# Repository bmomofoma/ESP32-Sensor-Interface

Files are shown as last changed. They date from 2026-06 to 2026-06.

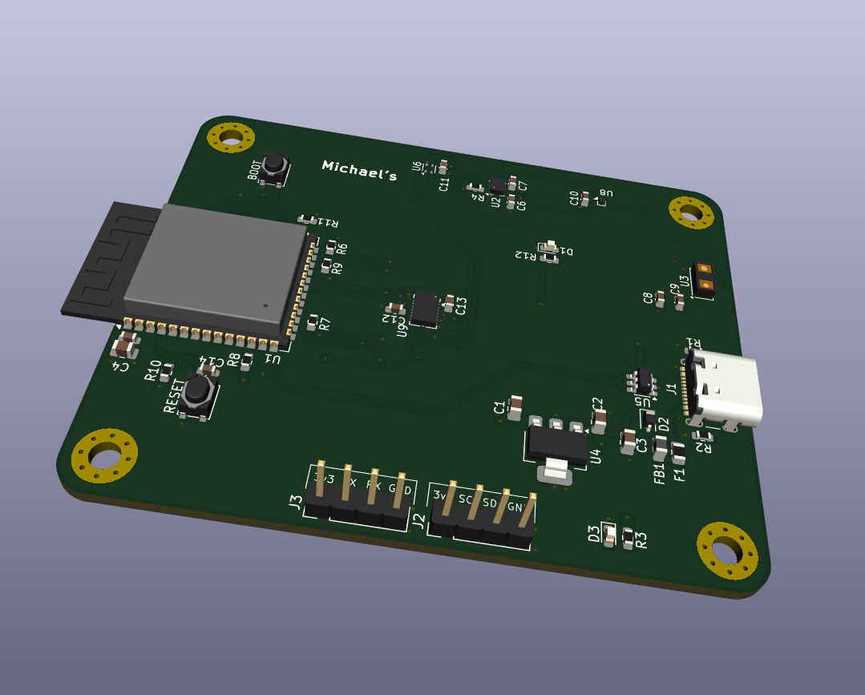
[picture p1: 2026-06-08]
assets/PCB view.png

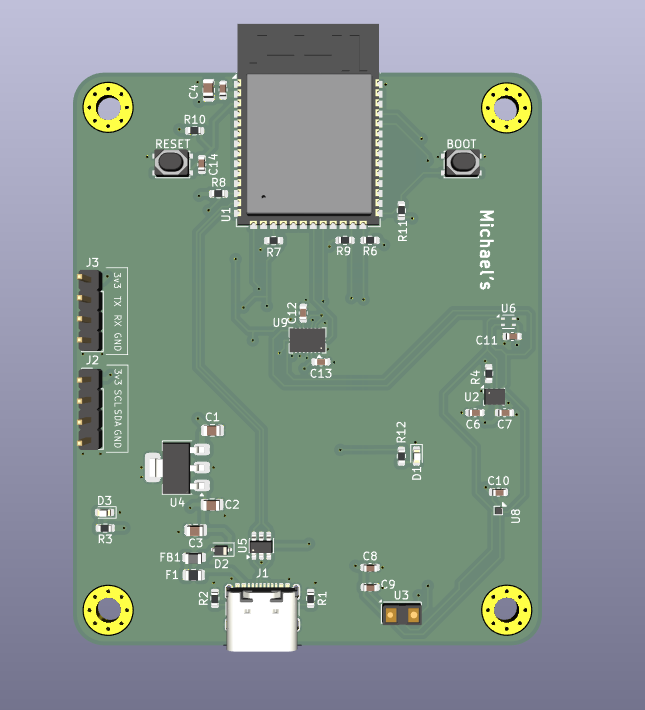
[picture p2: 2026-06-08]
assets/PCB top view.png

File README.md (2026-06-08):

# ESP32-S3 Sensor Hub

I built this board because I wanted a compact, reliable hardware platform that could pull data from five different sensors at the same time without turning the signal lines into a noisy mess. It’s a 4-layer board centered around an ESP32-S3 that acts as a central data hub, ideal for robotics or autonomous systems. 

---

## Why I Made These Design Choices

### Moving to a 4-Layer Board
A lot of simple projects stick to 2 layers, but running high-frequency data lines right next to power traces is a recipe for a noisy bus. 
* I made **Layer 2 a solid Ground plane** to give all the signals a tight, clean return path, which knocks down cross-talk immensely.
* **Layer 3 is a power plane**, which lets me cleanly route the 3.3V regulated line without running into routing bottlenecks.

### Powering the Array Safely
The board takes 5V from a USB-C port and drops it to 3.3V using an `AP7361C-33E` linear regulator. 
* The ESP32-S3 spikes in current when its Wi-Fi or Bluetooth radios kick on. This regulator can handle up to 1A, keeping the rail steady so the sensors don't glitch.
* For debugging safety, I put a ferrite bead, a Schottky diode, and a resettable polyfuse on the input to protect the expensive components downstream if I accidentally short something on the bench.

### Choosing Flat Pads (ENIG) over HASL
Two of the sensors—the `BMI088` IMU and the `MMC5633NJL` magnetometer—come in fine-pitch LGA and QFN packages, meaning the pins are tiny and sit entirely underneath the chip. 
* Standard HASL board finishes leave uneven mounds of solder on the pads, which causes these tiny chips to float or bridge during soldering. 
* I specified an **ENIG (Gold) finish** for manufacturing because it guarantees perfectly flat pads, making reflow much easier.

---

## The Hardware Setup

All five sensors communicate over a single shared $\text{I}^2\text{C}$ bus using **GPIO8 (SDA)** and **GPIO9 (SCL)**, pulled up by $4.7\text{ k}\Omega$ resistors.

| Sensor | Part Number | What It Measures |
| :--- | :--- | :--- |
| **IMU (6-Axis)** | BMI088 | Pitch, roll, yaw, and high-G acceleration |
| **Magnetometer** | MMC5633NJL | Compass heading orientation |
| **Pressure/Altimeter** | BMP280 | Altitude & atmospheric pressure |
| **Temp/Humidity** | SHT4x | Local environmental data |
| **Time-of-Flight (ToF)** | VL53L0X | Precision optical distance for proximity |

> 🛠️ **Hardware Note:** The VL53L0X distance sensor hardcodes itself to address `0x29` on boot, which can cause bus issues. To fix this, I routed its hardware shutdown pin (**XSHUT**) to **GPIO48** so the firmware can hard-reset the chip and dynamically change its address if needed.

---

## Layout Constraints & Debugging

* **Antenna Keep-Out:** There is a strict, cross-hatched keep-out zone on all layers around the ESP32’s PCB antenna. No copper, traces, or mounting screws can go near it, keeping the wireless signal strong.
* **Lab Debugging Headers:** I exposed the $\text{I}^2\text{C}$ lines on header **J2** and the main serial UART lines on header **J3**. This makes it easy to clip on a logic analyzer or hook up a USB-to-UART bridge to watch terminal logs while writing firmware.
* **Buttons & LEDs:** Included a reset button, a boot button, a green power LED, and a red status LED mapped to **GPIO3** for basic visual debugging.

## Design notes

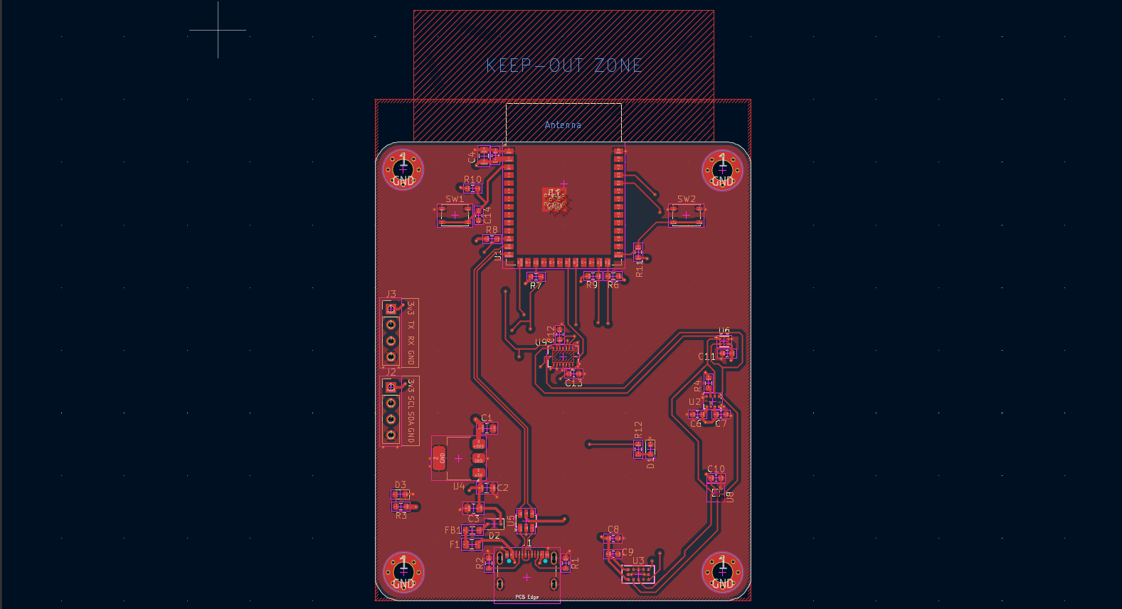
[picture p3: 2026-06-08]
assets/PCB-top-layer.png

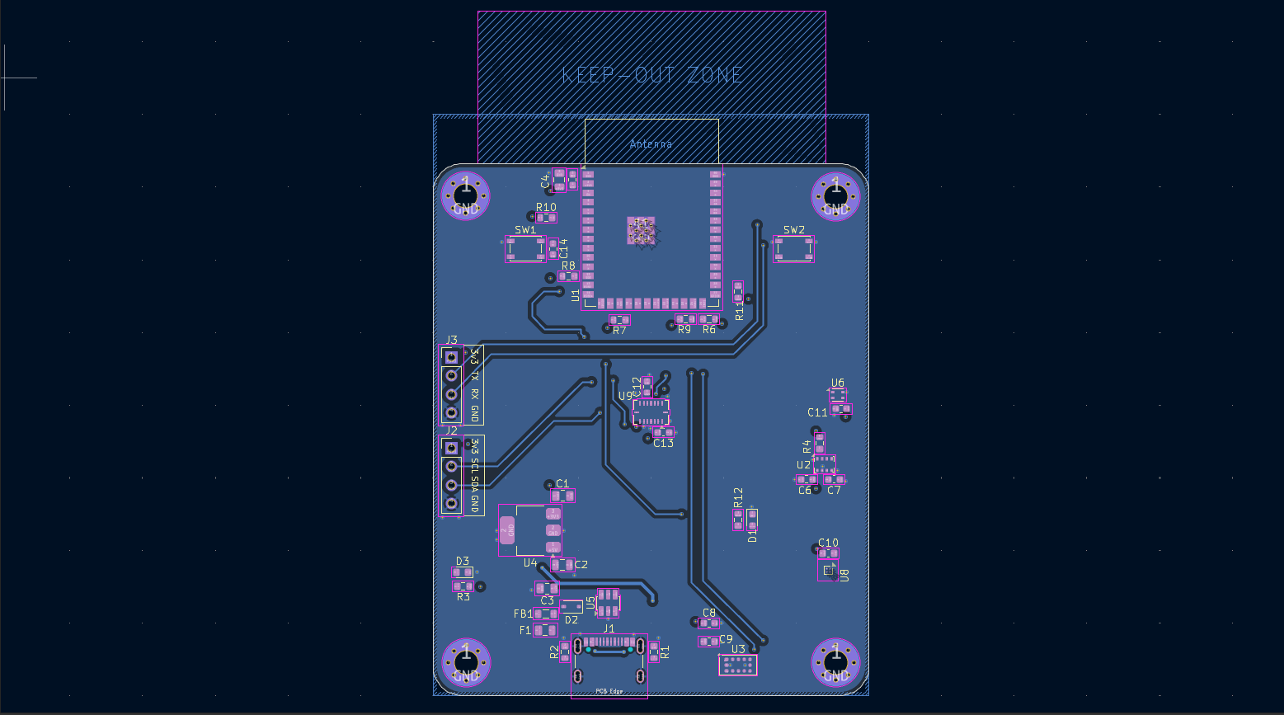
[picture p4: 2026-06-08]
assets/pcb-bottom-layer.png

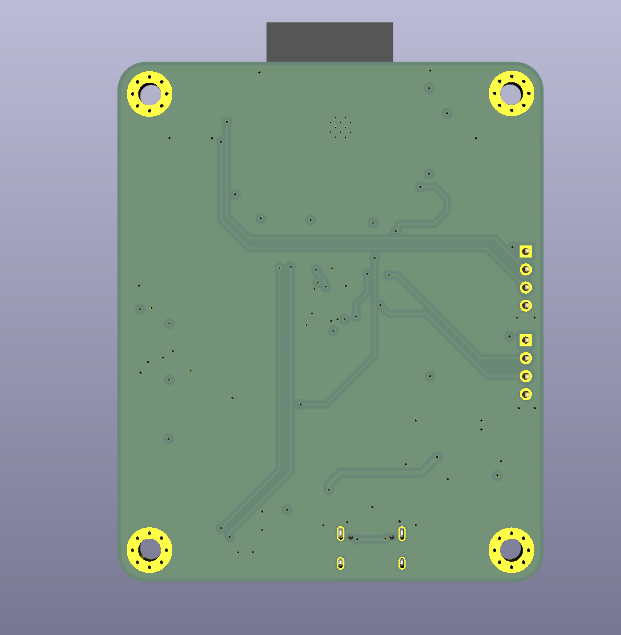
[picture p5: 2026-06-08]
assets/PCB bottom view.png

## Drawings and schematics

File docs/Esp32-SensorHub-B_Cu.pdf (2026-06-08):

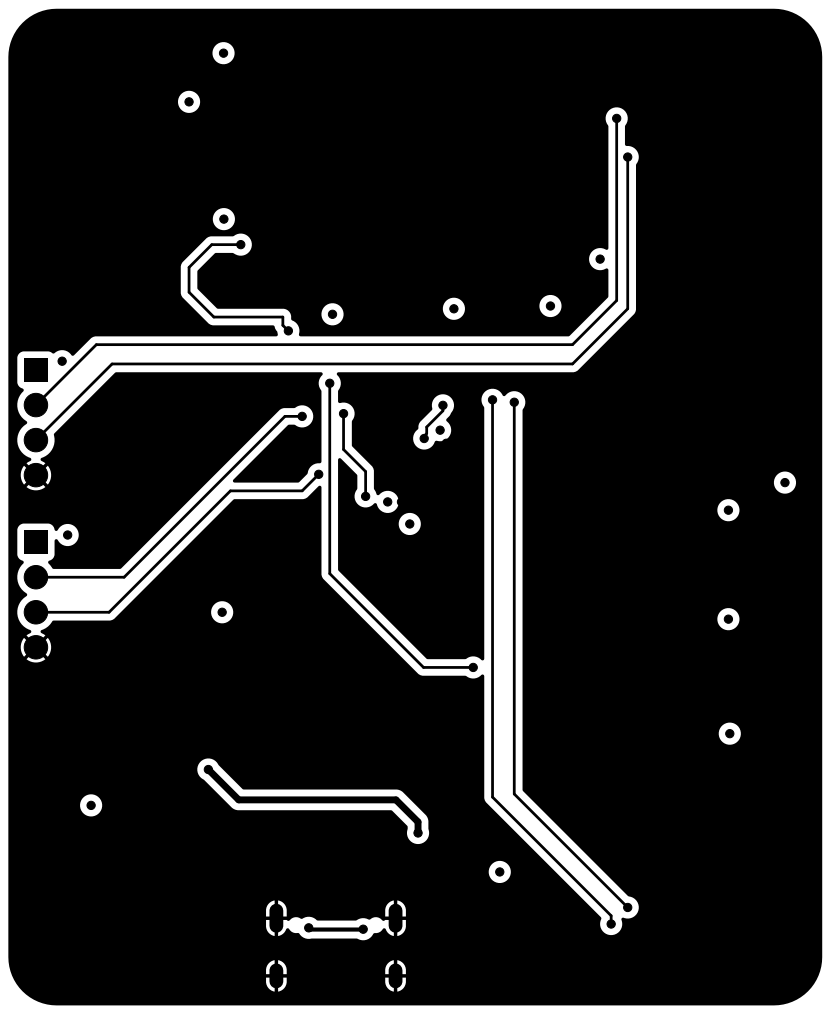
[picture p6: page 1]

Size: A4 | Rev:
KiCad E.D.A. 10.0.2 | Id: 4/5

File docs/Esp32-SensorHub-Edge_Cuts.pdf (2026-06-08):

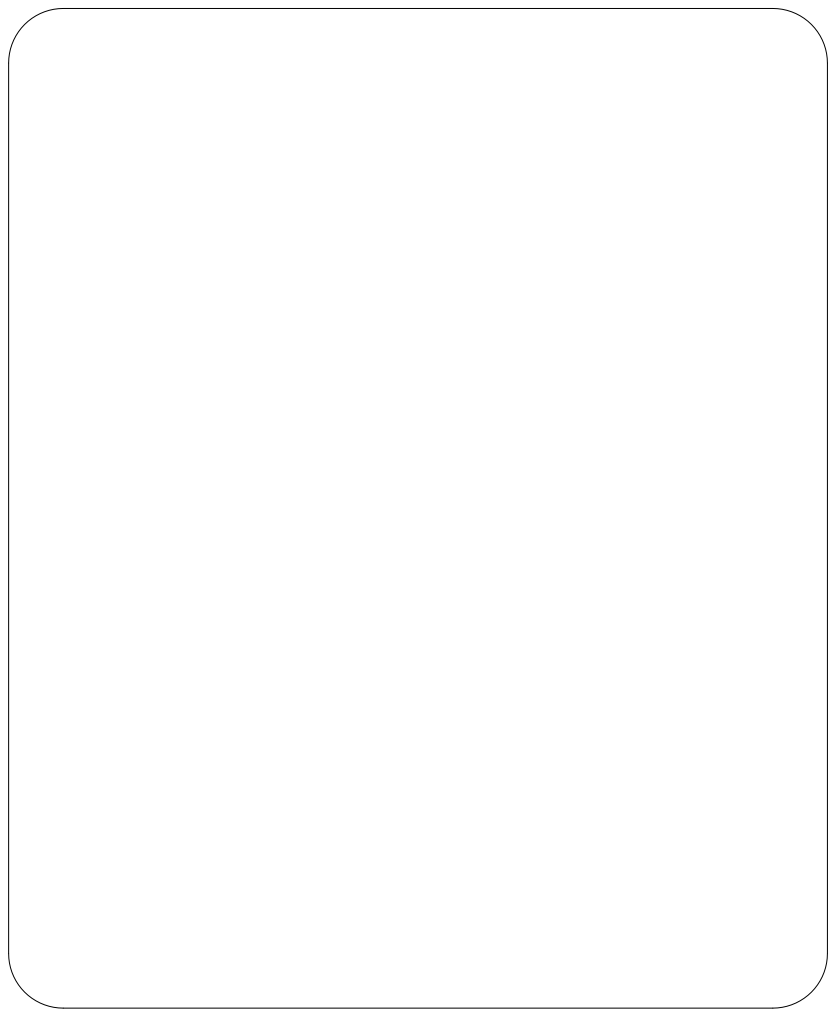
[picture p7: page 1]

Size: A4 | Rev:
KiCad E.D.A. 10.0.2 | Id: 5/5

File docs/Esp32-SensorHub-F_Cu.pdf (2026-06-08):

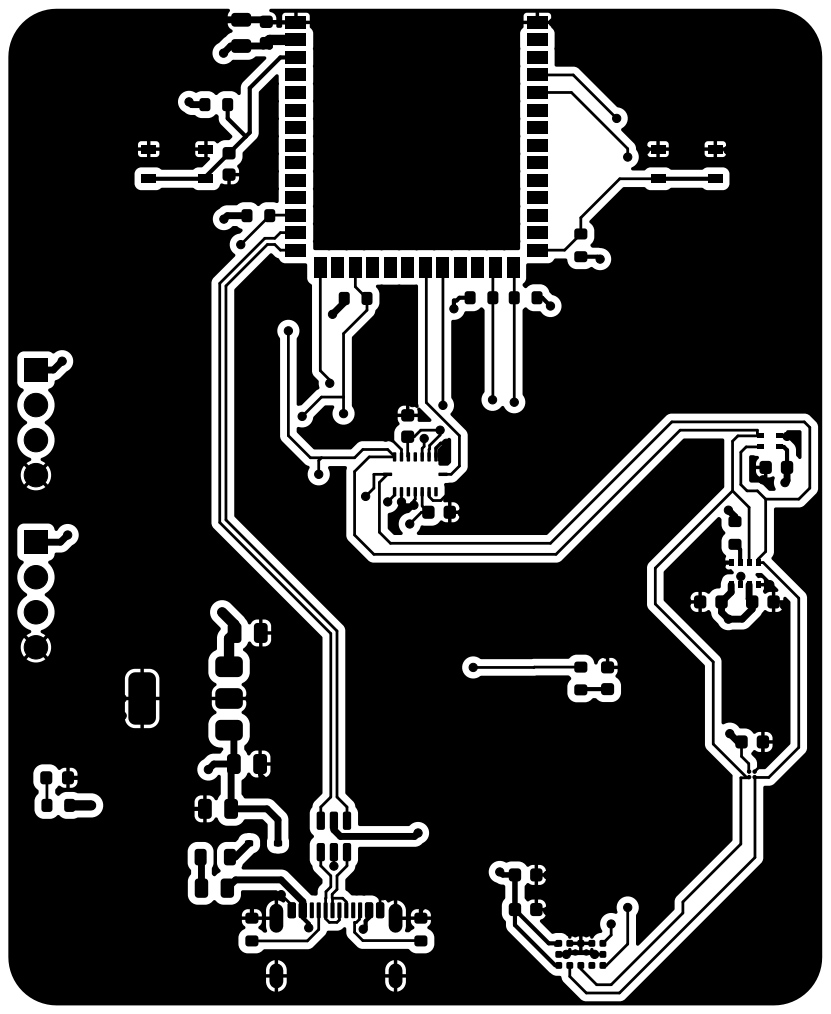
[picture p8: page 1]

Size: A4 | Rev:
KiCad E.D.A. 10.0.2 | Id: 1/5

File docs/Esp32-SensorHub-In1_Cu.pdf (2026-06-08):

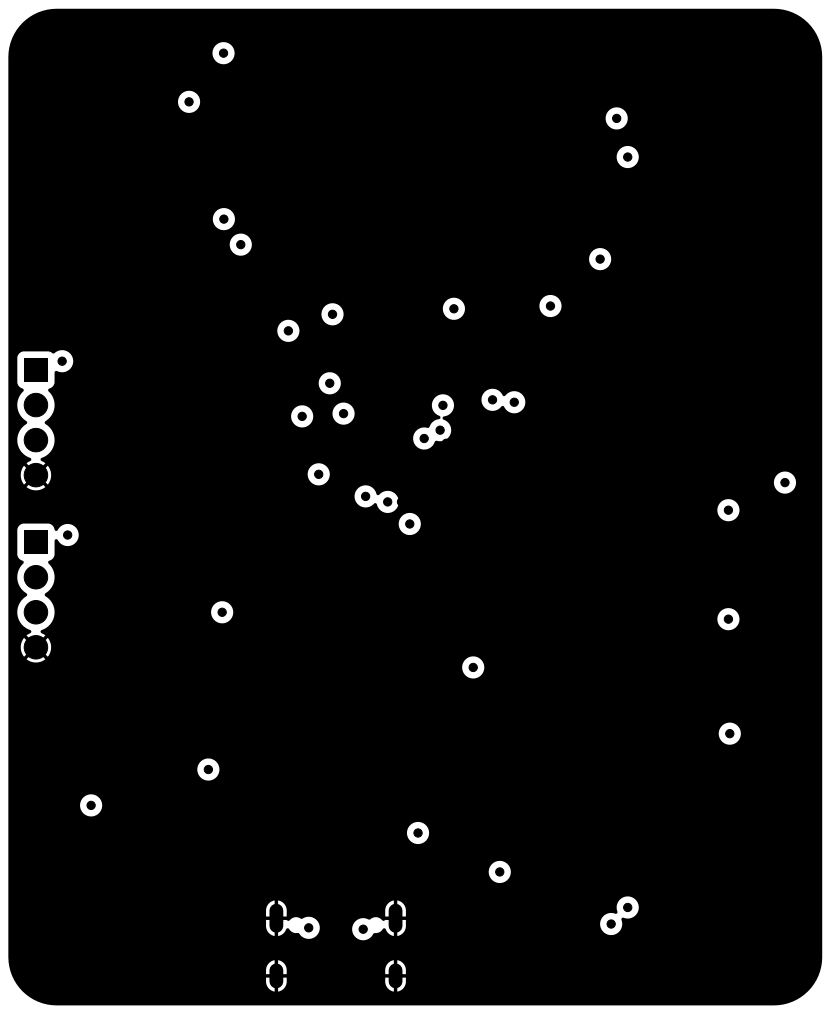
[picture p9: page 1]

Size: A4 | Rev:
KiCad E.D.A. 10.0.2 | Id: 2/5

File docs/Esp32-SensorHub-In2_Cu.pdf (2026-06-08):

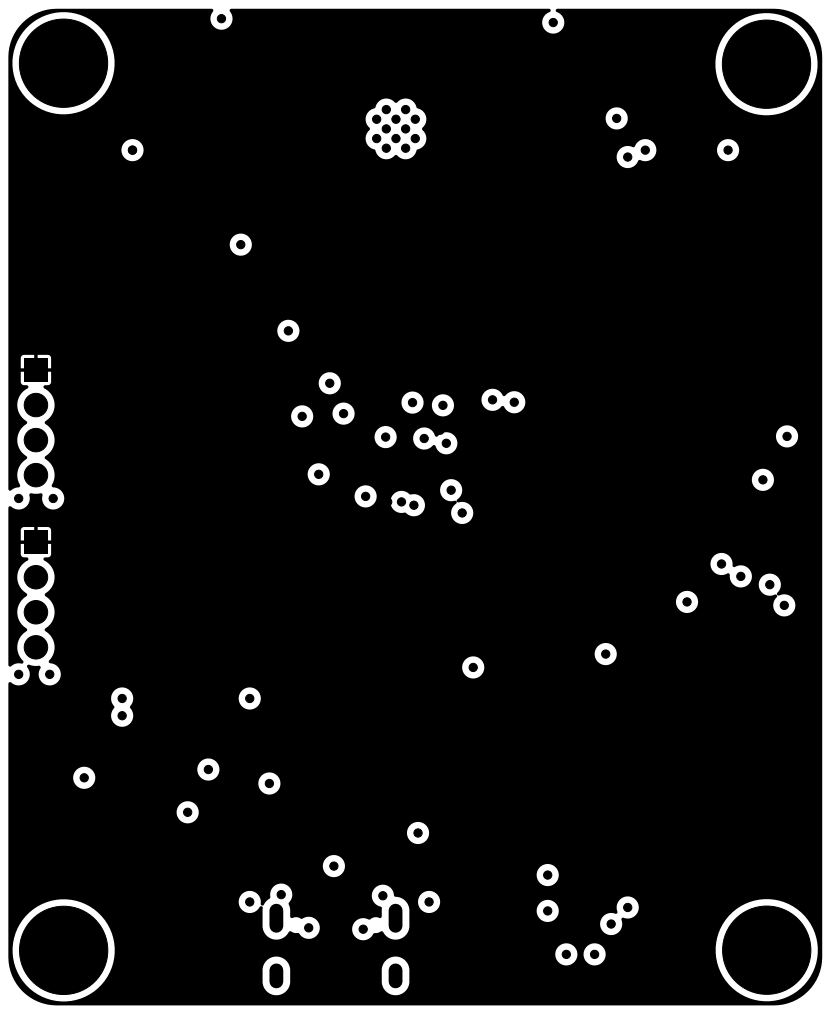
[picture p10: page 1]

Size: A4 | Rev:
KiCad E.D.A. 10.0.2 | Id: 3/5

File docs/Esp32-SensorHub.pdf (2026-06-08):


Size: A4 | Rev:
KiCad E.D.A. 10.0.2 | Id: 1/5





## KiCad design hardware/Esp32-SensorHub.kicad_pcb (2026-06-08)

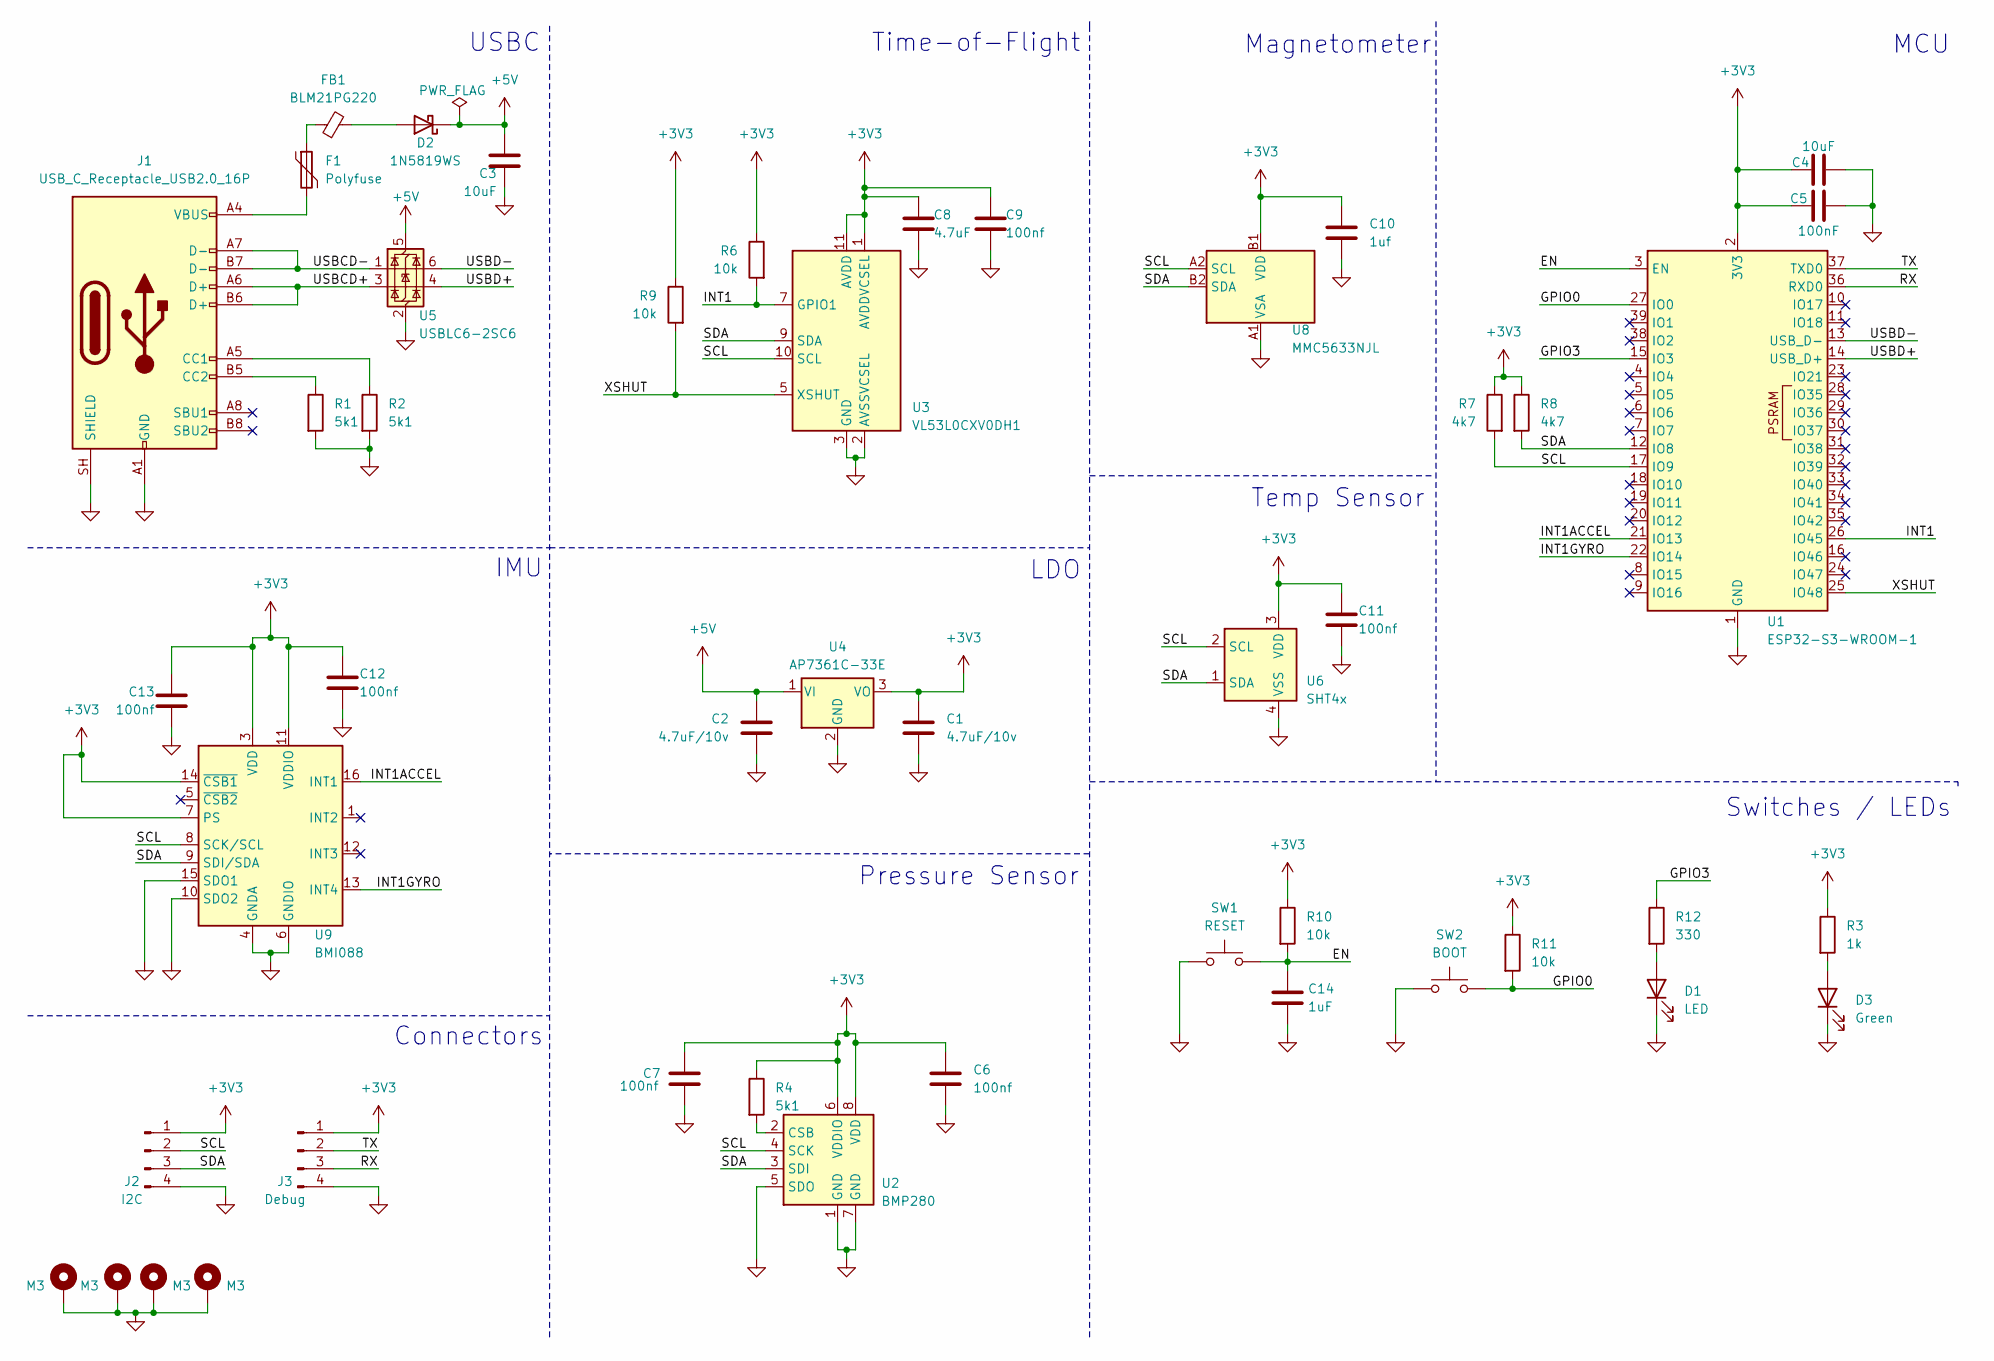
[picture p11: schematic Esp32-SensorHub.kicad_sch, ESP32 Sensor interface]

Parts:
C1, C2: 4.7uF/10v; C_0805_2012Metric
C3, C4: 10uF; C_0805_2012Metric
C5: 100nF; C_0603_1608Metric
C6, C7, C9, C11, C12, C13: 100nf; C_0603_1608Metric
C8: 4.7uF; C_0603_1608Metric
C10: 1uf; C_0603_1608Metric
C14: 1uF; C_0603_1608Metric
D1: LED; LED_0603_1608Metric
D2: 1N5819WS; D_SOD-323
D3: Green; LED_0603_1608Metric
F1: Polyfuse; Fuse_0805_2012Metric
FB1: BLM21PG220; L_0805_2012Metric
H1, H2, H3, H4: M3; MountingHole_3.2mm_M3_Pad_Via
J1: USB_C_Receptacle_USB2.0_16P; USB_C_Receptacle_GCT_USB4105-xx-A_16P_TopMnt_Horizontal
J2: I2C; PinHeader_1x04_P2.54mm_Vertical
J3: Debug; PinHeader_1x04_P2.54mm_Vertical
R1, R2, R4: 5k1; R_0603_1608Metric
R3: 1k; R_0603_1608Metric
R6, R9, R10, R11: 10k; R_0603_1608Metric
R7, R8: 4k7; R_0603_1608Metric
R12: 330; R_0603_1608Metric
SW1: RESET; SW_SPST_PTS810
SW2: BOOT; SW_SPST_PTS810
U1: ESP32-S3-WROOM-1
U2: BMP280; Bosch_LGA-8_2x2.5mm_P0.65mm_ClockwisePinNumbering
U3: VL53L0CXV0DH1; ST_VL53L1x
U4: AP7361C-33E; SOT-223-3_TabPin2
U5: USBLC6-2SC6; SOT-23-6
U6: SHT4x; Sensirion_DFN-4_1.5x1.5mm_P0.8mm_SHT4x_NoCentralPad
U8: MMC5633NJL; WLP-4_0.86x0.86mm_P0.4mm
U9: BMI088; Bosch_LGA-16_4.5x3mm_P0.5mm_LayoutBorder7x1y_ClockwisePinNu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

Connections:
+3V3: C1.1, C4.1, C5.1, C6.1, C7.1, C8.1, C9.1, C10.1, C11.1, C12.1, C13.1, J2.1, J3.1, R3.1, R4.1, R6.1, R7.1, R8.1, R9.1, R10.1, R11.1, U1.2 (3V3), U2.6 (VDDIO), U2.8 (VDD), U3.1 (AVDDVCSEL), U3.11 (AVDD), U4.3 (VO), U6.3 (VDD), U8.B1 (VDD), U9.3 (VDD), U9.7 (PS), U9.11 (VDDIO), U9.14 (~CSB1)
+5V: C2.1, C3.1, D2.1 (K), U4.1 (VI), U5.5 (VBUS)
/EN: C14.2, R10.2, SW1.2, U1.3 (EN); also elsewhere on the board
/GPIO0: R11.2, SW2.2, U1.27 (IO0); also elsewhere on the board
/GPIO3: R12.1, U1.15 (IO3)
/INT1: R6.2, U1.26 (IO45), U3.7 (GPIO1)
/INT1ACCEL: U1.21 (IO13), U9.16 (INT1)
/INT1GYRO: U1.22 (IO14), U9.13 (INT4)
/RX: J3.3, U1.36 (RXD0)
/SCL: J2.2, R7.2, U1.17 (IO9), U2.4 (SCK), U3.10 (SCL), U6.2 (SCL), U8.A2 (SCL), U9.8 (SCK/SCL)
/SDA: J2.3, R8.2, U1.12 (IO8), U2.3 (SDI), U3.9 (SDA), U6.1 (SDA), U8.B2 (SDA), U9.9 (SDI/SDA)
/TX: J3.2, U1.37 (TXD0)
/USBCD+: J1.A6 (D+), J1.B6 (D+), U5.3 (I/O2)
/USBCD-: J1.A7 (D-), J1.B7 (D-), U5.1 (I/O1)
/USBD+: U1.14 (USB_D+), U5.4 (I/O2)
/USBD-: U1.13 (USB_D-), U5.6 (I/O1)
/XSHUT: R9.2, U1.25 (IO48), U3.5 (XSHUT)
GND: C1.2, C2.2, C3.2, C4.2, C5.2, C6.2, C7.2, C8.2, C9.2, C10.2, C11.2, C12.2, C13.2, C14.1, D1.1 (K), D3.1 (K), H1.1 (1_1), H2.1 (1_1), H3.1 (1_1), H4.1 (1_1), J1.A1 (GND), J1.A12 (GND), J1.B1 (GND), J1.B12 (GND), J1.SH (SHIELD), J2.4, J3.4, R1.2, R2.2, SW1.1, SW2.1, U1.1 (GND), U1.40 (GND), U1.41 (GND), U2.1 (GND), U2.5 (SDO), U2.7 (GND), U3.2 (AVSSVCSEL), U3.3 (GND), U3.4 (GND), U3.6 (GND), U3.12 (GND), U4.2 (GND), U5.2 (GND), U6.4 (VSS), U8.A1 (VSA), U9.2 (GNDA), U9.4 (GNDA), U9.6 (GNDIO), U9.10 (SDO2), U9.15 (SDO1); also elsewhere on the board
unnamed: D1.2 (A), R12.2
unnamed: D2.2 (A), FB1.2
unnamed: D3.2 (A), R3.2
unnamed: F1.1, FB1.1
unnamed: F1.2, J1.A4 (VBUS), J1.A9 (VBUS), J1.B4 (VBUS), J1.B9 (VBUS)
unnamed: J1.A5 (CC1), R2.1
unnamed: J1.B5 (CC2), R1.1
unnamed: R4.2, U2.2 (CSB)

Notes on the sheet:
Magnetometer
Pressure Sensor
USBC
Connectors
LDO
IMU
Temp Sensor
Switches / LEDs
Time-of-Flight
MCU

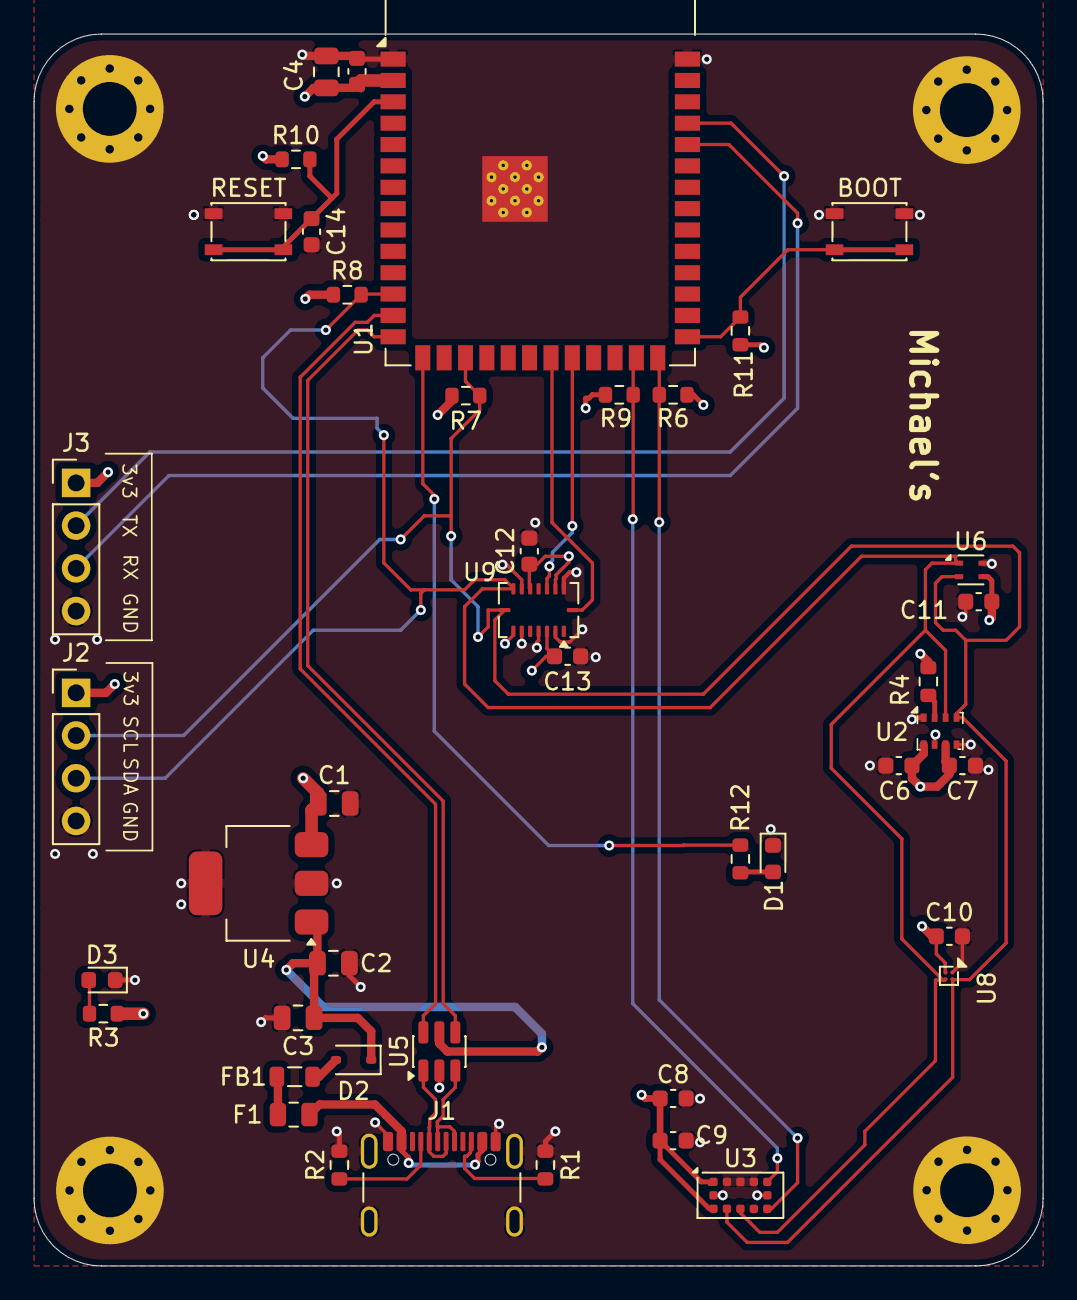
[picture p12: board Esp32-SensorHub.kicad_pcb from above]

Board: 4 copper layers, 60.0 x 73.2 mm, 47 parts (0 on the bottom side), 26 nets.

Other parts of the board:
BOOT: BOOT; SW_SPST_PTS810
RESET: RESET; SW_SPST_PTS810

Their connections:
/EN: RESET.2; also elsewhere on the board
/GPIO0: BOOT.2; also elsewhere on the board
GND: BOOT.1, RESET.1; also elsewhere on the board
